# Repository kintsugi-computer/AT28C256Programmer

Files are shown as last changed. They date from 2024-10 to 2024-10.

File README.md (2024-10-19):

# ATmega32u4 EEPROM Programmer for AT28C256 and compatibles 

This is a simple EEPROM programmer using an ATmega32u4.

I'm building the ZX81+38 clone of the Sinclair ZX81, to use for testing some
external interface boards I'm working on.

The ZX81+38 requires an (E)EPROM, and a ROM programmer. I don't have a ROM programmer but I do have an ATmega32u4 development board that I bought many years ago. The ATmega32u4 is a 5V MCU with 26 GPIOs and this can interface with the 26 signal pins of a AT8C256 (or compatble) EEPROM without the need for additional components, although I added a 1 nF coupling capacitor. I do not remember where I bought this Atmega32u4 board, and I cannot find any documentation on this particular board on the Internet. 

This project makes use of Dean Camera's excellent [LUFA USB stack](www.lufa-lib.org) to take advantage of the built-in USB support of the 
ATmega32u4. I copied the communication code using ringbuffers from the
[ATmega16u2 firmware project](https://github.com/KITcar-Team/kitcar-usbserial).
And finally, I used the [ATmega8 EEPROM programmer](https://github.com/wagiminator/ATmega-EEPROM-Programmer) as inspiration. The latter project requires shift registers to implement the parallel operation of the programmer and it uses the Arduino development system. In contrast, this project requires no additional components because the ATmega32u4 provides exactly the required 
number of GPIOs and it uses the avr-gcc framework.

The programmer can also be used to test RAM chips that have a pinout and
timing that is compatible with the AT28C256.

## Usage

### Overview

The ATmega32u4 MCU is used as a USB-connected programmer. It receives commands
to read or write bytes to a given address from the host computer over a serial connection and communicates to the ROM or RAM chip. When writing a byte it
will read back the value after writing to the address and return that to the host computer.

No attempt was made to optimize the speed of programming the ROM chips. The programmer writes each address individually and does not use block write operations. Writing a 32KiB takes only about 30 seconds and that seems fast enough for occasional use. Slower write operations are indicative of write errors.

Two Python scripts are provided that can send commands to the programmer. These scripts are used to upload or download blocks of data from the ROM and to test a ROM or RAM chip by writing and reading back different values to the ROM or RAM chip:

```
usage: AT28C256Programmer [-h] -d DEVICE [-i INPUT_FILE] [-o OUTPUT_FILE]
                          [-a ADDRESS] [-s SIZE] [-E] [-D]

Program an AT28C256 or compatible ROM chip using an Atmega32u4. Use the
-d/--device option to specify the serial device. Use the -i/--input_file
option to upload to the ROM. Use the -o/--output_file option to download from
the ROM. The -a/--adress option specifies the start address. This is optional
and defaults to 0. The -s/--size option specifies the size of the
upload/download. This is optional and defaults to the size of input file for
uploads and up to the end of the ROM's 32KB address space for downloads.

options:
  -h, --help            show this help message and exit
  -d DEVICE, --device DEVICE
                        The USB serial device for accessing the programmer.
  -i INPUT_FILE, --input_file INPUT_FILE
                        The ROM file to be uploaded.
  -o OUTPUT_FILE, --output_file OUTPUT_FILE
                        The file where to save the download.
  -a ADDRESS, --address ADDRESS
                        The start address for the upload or download.
  -s SIZE, --size SIZE  The size of the upload or download.
  -E, --sdp_enable      Enable the software data protection after uploading.
  -D, --sdp_disable     Disable the software data protection before uploading.

```

This script supports disabling and enabling the Software Data Protection for AT28C256 ROM chips. The cheaper chips available on Ebay and from Chinese sellers are pre-owned and may have SDP enabled, as did the one I bought.

Note that one should always use the `-s` option when programming a ROM chip that has less than 32KiB capacity. For instance, use `-s 8192` when programming an AT28C64 EEPROM.

```

usage: RWTester [-h] -d DEVICE [-r REFERENCE] [-a ADDRESS] [-s SIZE] [-m MASK]

Test a ROM or RAM chip using an Atmega32u4. The ROM or RAM must be compatible
with the AT28C256 ROM chip. The program writes values to the ROM or RAM and
reads them back. The observed values are checked against the values that were
written. Use the -d/--device option to specify the USB serial device. The
-r/--reference option can be used to specify a file to compare to the contents
of the the ROM. The -a/--address option specifies the start address. This is
optional and defaults to 0. The -s/--size option specifies the size of the
block to test. This is optional and defaults 32KB. The optional argument
-m/--mask is an 8-bit integer that represents a bit mask. Only the bits that
are set in this mask are used in the comparisons.

options:
  -h, --help            show this help message and exit
  -d DEVICE, --device DEVICE
                        The USB serial device for accessing the programmer.
  -r REFERENCE, --reference REFERENCE
                        Compare the ROM contents against the given file.
  -a ADDRESS, --address ADDRESS
                        The start address for the test.
  -s SIZE, --size SIZE  The size of the block to test (in bytes).
  -m MASK, --mask MASK  Compare using the provided mask.
```

## Construction

The programmer was constructed on a small piece of protoboard using a ZIF socket and female headers. The ATmega32u4 development board had the pins soldered on top and it is therefore inserted upside-down in the headers:

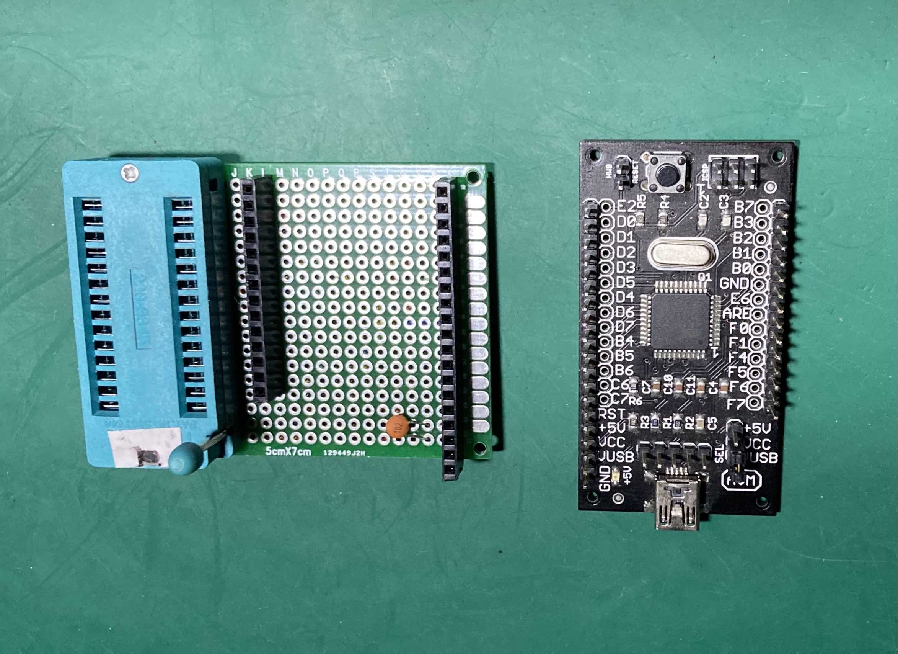
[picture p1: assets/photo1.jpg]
ATmega32u4 and protoboard

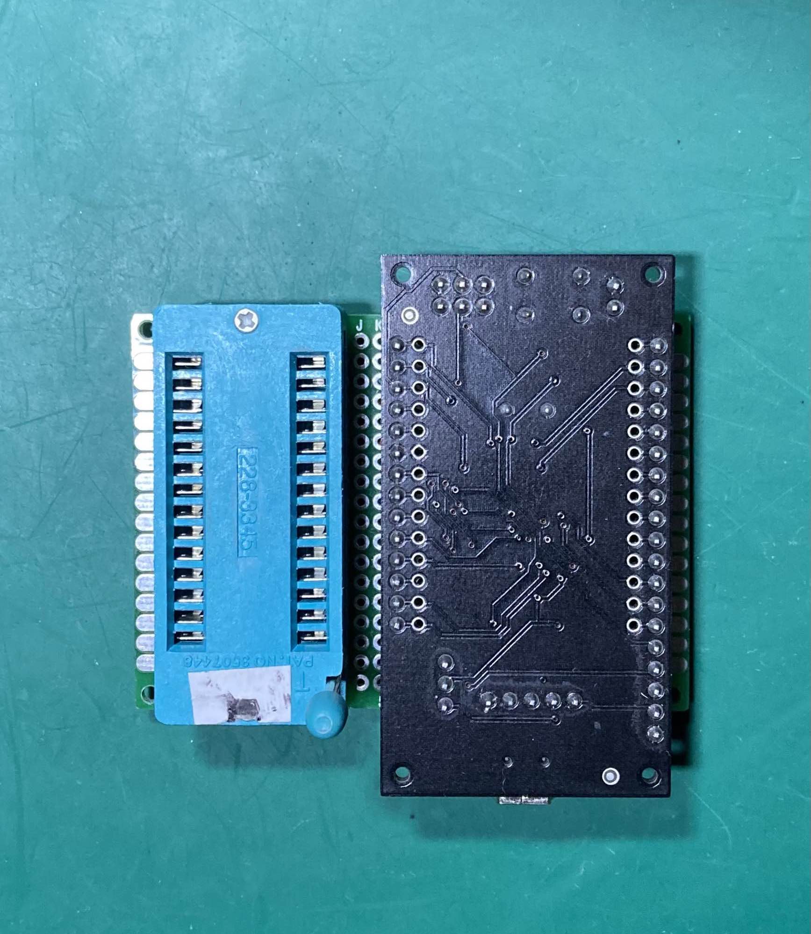
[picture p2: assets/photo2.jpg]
AT28C256Programmer


The programmer uses the available GPIO pins of port C and port F to connect to the datapins:

| GPIO 	| Data bus |
|---|---|
| F0		| D0		|
| F1		| D1		|
| C6		| D2		|
| C7		| D3		|
| F4		| D4		|
| F5		| D5		|
| F6		| D6		|
| F7		| D7		|

The address bus uses ports D and B:

| GPIO 	| Address bus |
|---|---|
| D0		| A0		|
| D1		| A1		|
| D6		| A2		|
| D7		| A3		|
| D4		| A4		|
| D5		| A5		|
| D6		| A6		|
| D7		| A7		|
| B0		| A8		|
| B1		| A9		|
| B2		| A10		|
| B3		| A11		|
| B4		| A12		|
| B5		| A13		|
| B6		| A14		|

The control signals make use of the remaning pins of port B and port E:

| GPIO 	| Signal  |
|---|---|
| B7		| /CE		|
| E2		| /OE		|
| E6		| /WE		|

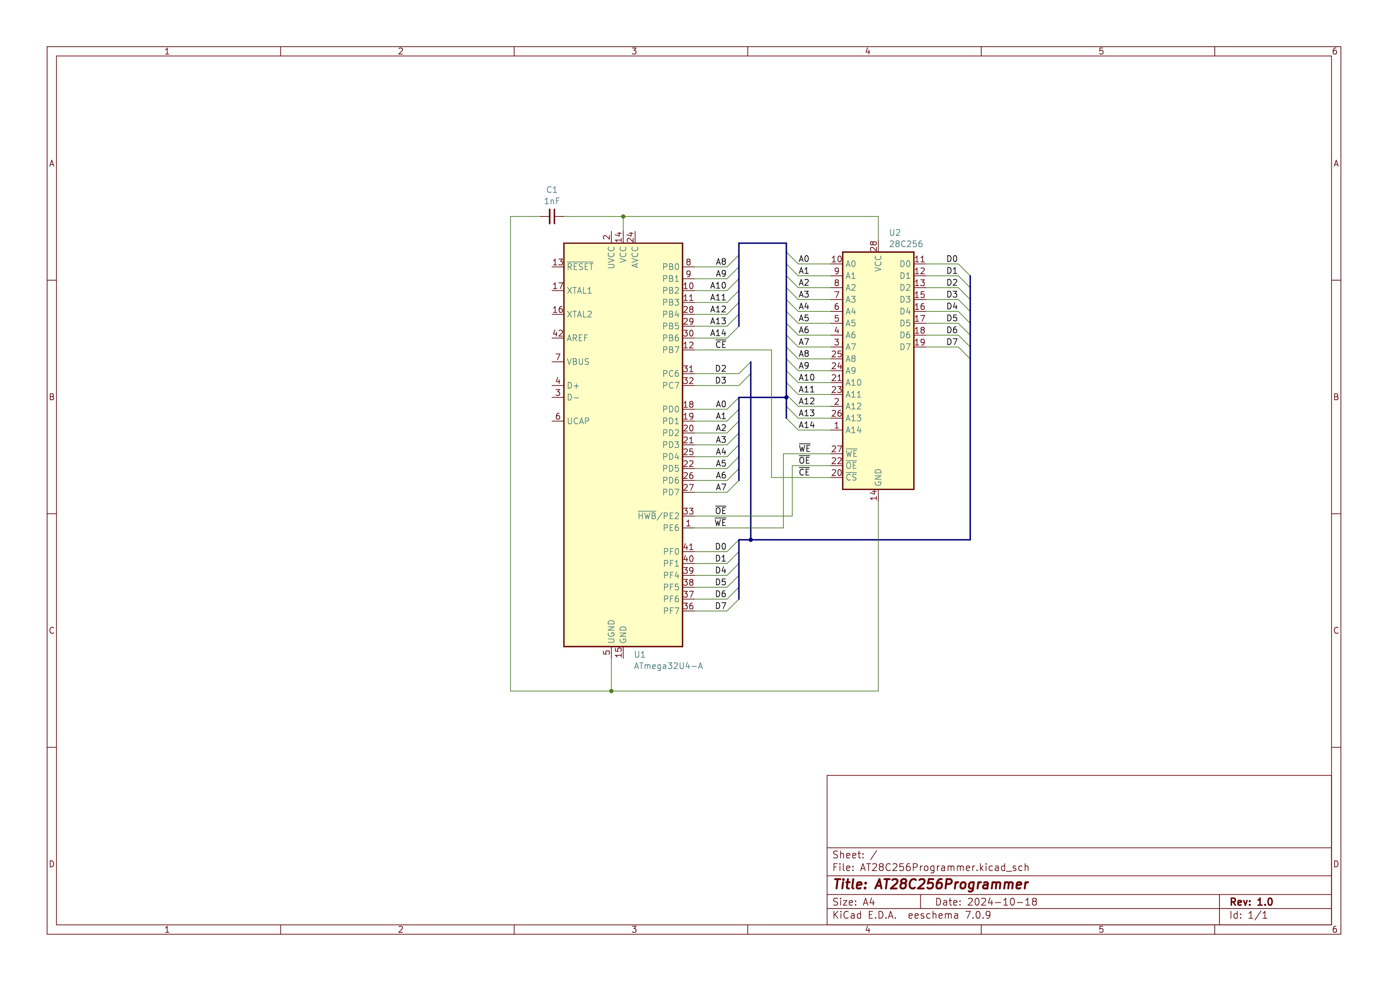
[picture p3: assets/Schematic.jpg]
Schematic


## Building and installing the project

### Firmware

To build this project, you will need to have the avr-gcc toolchain installed.
I used the [Mac OS AVR toolchain](https://github.com/beustens/avr-gcc_mac_toolchain.git). The directory that contains the executables must be added to your `PATH` environment variable.

LUFA can be downloaded from the [LUFA Github repository](https://github.com/abcminiuser/lufa.git). You should set the `LUFA_PATH` environment variable to the `LUFA` subdirectory of the repository. 

I installed the DFU programmer tool using [MacPorts](https://www.macports.org/):

```
$> sudo port install dfu-programmer
```

You will also need `make`. On MacOs this is installed as part of the XCode command line tools.

Build the project by running:

```
$> make
```

in the root directory of the project.

Attach the ATmega32u4 in DFU mode (HWB shorted when resetting the device) and 
program the device by running:

```
$> make dfu
```

### Python modules

The Python install package for Python3 is available in the `dist` subdirectory as a Python wheel. Install this using `pip3`:

```
$> pip3 install dist/at28c256programmer-0.1.0-py3-none-any.whl
```

This installs the pPython modules and the Python scripts.

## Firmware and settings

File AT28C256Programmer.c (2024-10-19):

/*

    This makes use of, and is based on:

             LUFA Library
     Copyright (C) Dean Camera, 2021.

  dean [at] fourwalledcubicle [dot] com
           www.lufa-lib.org

    And:

  https://github.com/KITcar-Team/kitcar-usbserial

    As well as:

  https://github.com/wagiminator/ATmega-EEPROM-Programmer

*/

/*
  Copyright 2021  Dean Camera (dean [at] fourwalledcubicle [dot] com)

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
  The author disclaims all warranties with regard to this
  software, including all implied warranties of merchantability
  and fitness.  In no event shall the author be liable for any
  special, indirect or consequential damages or any damages
  whatsoever resulting from loss of use, data or profits, whether
  in an action of contract, negligence or other tortious action,
  arising out of or in connection with the use or performance of
  this software.
*/

/** \file
 *
 *  Main source file for the AT28C256Programmer project. This file contains 
 * the main tasks of  the project and is responsible for the initial 
 * application hardware configuration.
 */

#include "AT28C256Programmer.h"

/** Circular buffer to hold data from the host before it is sent to the 
 * device via the serial port. 
 */
static RingBuffer_t USB_Incoming_Buffer;

/** Underlying data buffer for \ref USB_Incoming_Buffer, where the stored 
 * bytes are located. 
 */
static uint8_t      USB_Incoming_Buffer_Data[10];

/** Circular buffer to hold data from the serial port before it is sent to 
 * the host. 
 */
static RingBuffer_t USB_Outgoing_Buffer;

/** Underlying data buffer for \ref USB_Outgoing_Buffer, where the stored 
 * bytes are located. 
 */
static uint8_t      USB_Outgoing_Buffer_Data[10];

/** LUFA CDC Class driver interface configuration and state information. 
 * This structure is
 *  passed to all CDC Class driver functions, so that multiple instances of 
 * the same class
 *  within a device can be differentiated from one another.
 */
USB_ClassInfo_CDC_Device_t VirtualSerial_CDC_Interface =
	{
		.Config =
			{
				.ControlInterfaceNumber         = INTERFACE_ID_CDC_CCI,
				.DataINEndpoint                 =
					{
						.Address                = CDC_TX_EPADDR,
						.Size                   = CDC_TXRX_EPSIZE,
						.Banks                  = 1,
					},
				.DataOUTEndpoint                =
					{
						.Address                = CDC_RX_EPADDR,
						.Size                   = CDC_TXRX_EPSIZE,
						.Banks                  = 1,
					},
				.NotificationEndpoint           =
					{
						.Address                = CDC_NOTIFICATION_EPADDR,
						.Size                   = CDC_NOTIFICATION_EPSIZE,
						.Banks                  = 1,
					},
			},
	};


/** Main program entry point. This routine contains the overall program flow, 
 * including initial
 *  setup of all components and the main program loop.
 */
int main(void)
{
	SetupHardware();

	RingBuffer_InitBuffer(
        &USB_Incoming_Buffer, 
        USB_Incoming_Buffer_Data, 
        sizeof(USB_Incoming_Buffer_Data)
    );
	RingBuffer_InitBuffer(
        &USB_Outgoing_Buffer, 
        USB_Outgoing_Buffer_Data, 
        sizeof(USB_Outgoing_Buffer_Data)
    );

	GlobalInterruptEnable();

	for (;;)
	{

		/* Only try to read in bytes from the CDC interface if the transmit 
         * buffer is not full 
         */
		if (!(RingBuffer_IsFull(&USB_Incoming_Buffer)))
		{
			int16_t ReceivedByte = CDC_Device_ReceiveByte(
                &VirtualSerial_CDC_Interface
            );

			/* Store received byte into the USART transmit buffer 
             */
			if (!(ReceivedByte < 0))
			  RingBuffer_Insert(&USB_Incoming_Buffer, ReceivedByte);
		}

		uint16_t BufferCount = RingBuffer_GetCount(&USB_Outgoing_Buffer);
		if (BufferCount)
		{
			Endpoint_SelectEndpoint(
                VirtualSerial_CDC_Interface.Config.DataINEndpoint.Address
            );

			/* Check if a packet is already enqueued to the host - if so, we 
             * shouldn't try to send more data until it completes as there 
             * is a chance nothing is listening and a lengthy timeout could 
             * occur 
             */
			if (Endpoint_IsINReady())
			{
				/* Never send more than one bank size less one byte to the 
                 * host at a time, so that we don't block while a Zero Length 
                 * Packet (ZLP) to terminate the transfer is sent if the host 
                 * isn't listening 
                 */
				uint8_t BytesToSend = MIN(BufferCount, (CDC_TXRX_EPSIZE - 1));

				/* Read bytes from the USART receive buffer into the USB IN 
                 * endpoint i
                 */
				while (BytesToSend--)
				{
					/* Try to send the next byte of data to the host, abort 
                     * if there is an error without dequeuing 
                     */
					if (
                        CDC_Device_SendByte(
                            &VirtualSerial_CDC_Interface,
                            RingBuffer_Peek( &USB_Outgoing_Buffer)
                        ) != ENDPOINT_READYWAIT_NoError
                    ) {
						break;
					}

					/* Dequeue the already sent byte from the buffer now we 
                     * have confirmed that no transmission error occurred 
                     */
					RingBuffer_Remove(&USB_Outgoing_Buffer);
				}
			}
		}

        ProcessBuffer();

		CDC_Device_USBTask(&VirtualSerial_CDC_Interface);
		USB_USBTask();
	}
}

/** Configures the board hardware and chip peripherals for the demo's 
 * functionality. 
 */
void SetupHardware(void)
{
	/* Disable watchdog if enabled by bootloader/fuses 
     */
	MCUSR &= ~(1 << WDRF);
	wdt_disable();

    /* Disable JTAG
     */
    MCUCR |= 0x80; // disable JTAG interface
    MCUCR |= 0x80; // Have to tell twice

	/* Disable clock division 
     */
	clock_prescale_set(clock_div_1);

	/* Hardware Initialization 
     */
	USB_Init();
    GPIO_Init();
}

/** Event handler for the library USB Connection event. 
 */
void EVENT_USB_Device_Connect(void) {
}

/** Event handler for the library USB Disconnection event. 
 */
void EVENT_USB_Device_Disconnect(void) {
}

/** Event handler for the library USB Configuration Changed event. 
 */
void EVENT_USB_Device_ConfigurationChanged(void) {
	bool ConfigSuccess = true;

	ConfigSuccess &= CDC_Device_ConfigureEndpoints(
        &VirtualSerial_CDC_Interface
    );
}

/** Event handler for the library USB Control Request reception event. 
 */
void EVENT_USB_Device_ControlRequest(void) {
	CDC_Device_ProcessControlRequest(&VirtualSerial_CDC_Interface);
}

void GPIO_Init(void) {

    // Pins E6 (/WE) and E2 (/OE) are outputs
    DDRE |= PORTE_PIN_MASK ;

    // Pull /OE and /WE high
    PORTE |= PORTE_PIN_MASK ;

    // All pins on port B are outputs
    DDRB = PORTB_PIN_MASK ;
    // Pull CE high, other outputs low
    PORTB = ~ CE_ACTIVE_LOW ;

    // All pins on port D are outputs
    DDRD = PORTD_PIN_MASK ;
    // Pull all pins low
    PORTD = ~ PORTD_PIN_MASK ;

    // Set the data pins of PORTC en PORTF as input (0)
    DDRC &= ~ PORTC_PIN_MASK ;
    DDRF &= ~ PORTF_PIN_MASK ;
    // Enable the pullup resistors
    PORTC |= PORTC_PIN_MASK ;
    PORTF |= PORTF_PIN_MASK ;
}

/** Process the command strings received from the host computer using a 
           simple state machine */
void ProcessBuffer(void) {

    static uint8_t state = GET_OPCODE;
    static uint8_t opcode;
    static uint16_t address;

    uint8_t byte ;

    if ( 
           !(RingBuffer_IsFull(&USB_Outgoing_Buffer)) 
        && !(RingBuffer_IsEmpty(&USB_Incoming_Buffer))
    ) {

        switch (state) {
            case GET_OPCODE :
                opcode = RingBuffer_Remove(&USB_Incoming_Buffer);
                state = GET_H_ADDRESS;
                if (opcode == SDP_ON) {
                    EnableSDP();
                    RingBuffer_Insert(&USB_Outgoing_Buffer, 'E');
                    state = GET_OPCODE ;
                } else if (opcode == SDP_OFF) {
                    RingBuffer_Insert(&USB_Outgoing_Buffer, 'D');
                    DisableSDP();
                    state = GET_OPCODE ;
                }
                break;
            case GET_H_ADDRESS:
                address = (RingBuffer_Remove(&USB_Incoming_Buffer) << 8);
                state = GET_L_ADDRESS;
                break;
            case GET_L_ADDRESS:
                address |= RingBuffer_Remove(&USB_Incoming_Buffer);
                state = READ_WRITE;
                break;
        }
    }

    if (state == READ_WRITE) {
        if (
               opcode == READ 
            && !(RingBuffer_IsFull(&USB_Outgoing_Buffer))
        ) {
            byte = ReadByteFromAddress(address) ;
            RingBuffer_Insert(&USB_Outgoing_Buffer, byte);
            state = GET_OPCODE ;
        } else if (
               opcode == WRITE 
            && !(RingBuffer_IsEmpty(&USB_Incoming_Buffer))
            && !(RingBuffer_IsFull(&USB_Outgoing_Buffer))
        ) {
            byte = RingBuffer_Remove(&USB_Incoming_Buffer) ;
            WriteByteToAddress( address, byte );
            DataPoll(address, byte);
            byte = ReadByteFromAddress(address) ;
            RingBuffer_Insert(&USB_Outgoing_Buffer, byte);
            state = GET_OPCODE ;
        }
    }
}

void WriteByteToAddress(uint16_t address, uint8_t byte) {

    PORTE |= PORTE_PIN_MASK;                // /OE and /WE are high

    // Set the address and set /CE to low
    // Note that B7 is used to set /CE
    // Address space is limited to 32K, B7 is 0
    PORTD =  (address & PORTD_PIN_MASK);          // set low address bits
    PORTB = ((address >> 8) & CE_ACTIVE_LOW ) ;  // set high address bts + /CE

    // Set the data pins to output (to high)
    DDRC |= PORTC_PIN_MASK ;
    DDRF |= PORTF_PIN_MASK ;

    // Initialize the data pins as zero
    PORTC &= ~ PORTC_PIN_MASK ;
    PORTF &= ~ PORTF_PIN_MASK ;

    // Set the data pins for the bits that are 1
    PORTF |=   byte & PORTF_PIN_MASK ;
    PORTC |= ((byte & ~ PORTF_PIN_MASK) << 4) ;

    // Pull /WE low, /OE is high
    PORTE &= WE_ACTIVE_LOW ;        // /WE

    // >100ns delay
    _delay_us(1) ;

    PORTE |= PORTE_PIN_MASK;                // /OE and /WE are high

    // Pull /CE high and release address bus
    PORTB |= ~ CE_ACTIVE_LOW ;
    PORTD |= ~ PORTD_PIN_MASK ;

}

bool DataPoll(uint16_t address, uint8_t byte) {

    // Finish if the byte value is observed when
    // reading from the address, or when 10 ms 
    // have elapsed.

    uint8_t received ;

    for (uint16_t i = 0; i < 2500; i++) {
        received = ReadByteFromAddress(address);
        if ( received == byte) {
            return received;
        }
    }

    return received;
}

uint8_t ReadByteFromAddress(uint16_t address) {

    uint8_t byte = 0;

    PORTE |= PORTE_PIN_MASK;                // /OE and /WE are high

    // Set the address
    PORTD = (address & PORTD_PIN_MASK);           // Set low address byte 
    // Set high address bits and CE is high
    PORTB = (~ CE_ACTIVE_LOW | ((address >> 8) & CE_ACTIVE_LOW));

    // Set the relevant data pins as input (0)
    DDRC &= ~ PORTC_PIN_MASK ;
    DDRF &= ~ PORTF_PIN_MASK ;
    // Enable the pullup resistors
    PORTC |= PORTC_PIN_MASK ;
    PORTF |= PORTF_PIN_MASK ;

    // /OE is pulled low
    PORTE &= OE_ACTIVE_LOW ;        // /OE
    // /CE is pulled low
    PORTB &= CE_ACTIVE_LOW ;    // /CE is low

    // wait >100 ns
    _delay_us(1);
    
    // Read the input registers into the byte
    byte = ((PINC & PORTC_PIN_MASK) >> 4) ;
    byte |= (PINF & PORTF_PIN_MASK) ;

    // /OE is pulled high (and /WE)
    PORTE |= PORTE_PIN_MASK ;

    // Pull /CE high and release address bus
    PORTB |= ~ CE_ACTIVE_LOW ;
    PORTD |= ~ PORTD_PIN_MASK ;

    return byte;
}

void EnableSDP(void) {
    // Assumption: /OE is high
    WriteByteToAddress(0x5555, 0xAA);
    WriteByteToAddress(0x2AAA, 0x55);
    WriteByteToAddress(0x5555, 0xA0);
}

void DisableSDP(void) {
    // Assumption: /OE is high
    WriteByteToAddress(0x5555, 0xAA);
    WriteByteToAddress(0x2AAA, 0x55);
    WriteByteToAddress(0x5555, 0x80);
    WriteByteToAddress(0x5555, 0xAA);
    WriteByteToAddress(0x2AAA, 0x55);
    WriteByteToAddress(0x5555, 0x20);
}

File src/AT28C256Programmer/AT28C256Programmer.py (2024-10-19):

#!/usr/bin/env python3
# vim: tabstop=8 expandtab shiftwidth=4 softtabstop=4

import sys
import serial
import argparse

READ = ord('r')
WRITE = ord('w')
SDP_ON = ord('e')
SDP_OFF = ord('d')

ROMSIZE = 32768

class AT28C256Programmer:

    def __init__(self, 
        device, 
        input_file="", 
        output_file="", 
        address=0, 
        size=0, 
        sdp_enable=False,
        sdp_disable=False,
    ):
        self.device = device
        self.input_file = input_file
        self.output_file = output_file
        self.address = address
        self.size = size
        self.buffer = bytearray(4)
        self.sdp_enable = sdp_enable
        self.sdp_disable = sdp_disable
        self.ok = True

    def __call__(self):
        self.serial = serial.Serial(
            self.device, '115200', 
            serial.EIGHTBITS,
            serial.PARITY_NONE, 
            serial.STOPBITS_ONE
        )
        self.serial.timeout = 1

        if self.sdp_disable:
            self.disable_sdp()

        if self.input_file:
            with open(self.input_file, 'rb') as fd:
                rom = fd.read()
            self.upload_rom(rom)
            if self.ok:
                print(f"Uploaded ROM from {self.input_file}.")
            else:
                print(f"Error in uploading ROM from {self.input_file}.")

        elif self.output_file:
            with open(self.output_file, 'wb') as fd:
                self.download_rom(fd)
            print(f"Saved download to {self.output_file}.")

        elif not self.enable_sdp:
            print("No input or output file was specified. Exiting.")
            sys.exit(1)

        if self.sdp_enable:
            self.enable_sdp()

    def upload_rom(self, rom):
        rom_size = len(rom)
        if self.size:
            max_address = min(self.address+self.size, ROMSIZE) 
        else:
            max_address = min(self.address+rom_size, ROMSIZE)

        print(f"Uploading {self.input_file}")
        for (idx, address) in enumerate(range(self.address, max_address)):
            if (address % 1024) == 0:
                print(f" > {address}")
            self.write_byte(address, rom[idx])
        print(f" < {address}")

    def write_byte(self, address, byte):
            self.buffer[0] = WRITE
            self.buffer[1] = (address >> 8) & 0x7F
            self.buffer[2] = address & 0xFF
            self.buffer[3] = byte
            self.serial.write(self.buffer)
            check_byte = self.serial.read(1)

            if check_byte == "":
                raise Exception("No response from programmer")
            if check_byte != byte.to_bytes(1, "big"):
                self.ok = False

    def download_rom(self, fd):
        if self.size:
            max_address = min(self.address+self.size, ROMSIZE) 
        else:
            max_address = ROMSIZE

        print(f"Downloading {self.address} to {max_address-1}")

        for address in range(self.address, max_address):
            if (address % 1024) == 0:
                print(f" > {address} {'OK' if self.ok else 'FAIL'}")
            fd.write(self.read_byte(address))
        print(f" < {address} {'OK' if self.ok else 'FAIL'}")

    def read_byte(self, address):
        self.buffer[0] = READ
        self.buffer[1] = (address >> 8) & 0x7F
        self.buffer[2] = address & 0xFF
        self.serial.write(self.buffer[0:3])
        byte = self.serial.read(1)
        if byte == "":
            raise Exception("No response from programmer")
        return byte

    def enable_sdp(self):
        self.buffer[0] = SDP_ON
        self.serial.write(self.buffer[0:1])
        response = self.serial.read(1)
        print(f"Enabled SDP: {response}")
        
    def disable_sdp(self):
        self.buffer[0] = SDP_OFF
        self.serial.write(self.buffer[0:1])
        response = self.serial.read(1)
        print(f"Disabled SDP: {response}")

def options():
    parser = argparse.ArgumentParser(
                description="Program an AT28C256 or compatible ROM chip "
        "using an Atmega32u4. "
        "Use the -d/--device option to specify the serial device. Use "
        "the -i/--input_file option to upload to the ROM. Use the "
        "-o/--output_file option to download from the ROM. The -a/--adress "
        "option specifies the start address. This is optional and defaults to 0. "
        "The -s/--size option specifies the size of the upload/download. "
        "This is optional and defaults to the size of input file for uploads "
        "and up to the end of the ROM's 32KB address space for downloads."
    )

    parser.add_argument("-d", "--device", required=True, action="store",
            help="The USB serial device for accessing the programmer.")
    parser.add_argument("-i", "--input_file", required=False, action="store",
            default="", help="The ROM file to be uploaded.")
    parser.add_argument("-o", "--output_file", required=False, action="store",
            default="", help="The file where to save the download.")
    parser.add_argument("-a", "--address", required=False, action="store",
            type=int, default=0, 
            help="The start address for the upload or download.")
    parser.add_argument("-s", "--size", required=False, action="store",
            type=int, default=0, help="The size of the upload or download.")
    parser.add_argument("-E", "--sdp_enable", required=False, 
            action="store_true",
            help="Enable the software data protection after uploading.")
    parser.add_argument("-D", "--sdp_disable", required=False, 
            action="store_true",
            help="Disable the software data protection before uploading.")
    return vars(parser.parse_args())

def main():
    AT28C256Programmer(**options())()

if __name__ == "__main__" :
    main()
